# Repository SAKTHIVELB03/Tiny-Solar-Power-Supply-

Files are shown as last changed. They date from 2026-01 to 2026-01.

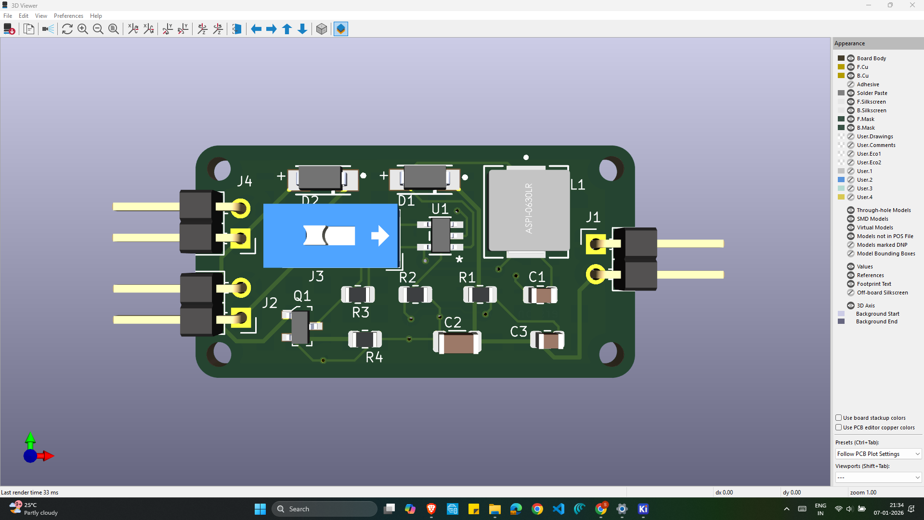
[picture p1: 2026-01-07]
3d model top.png

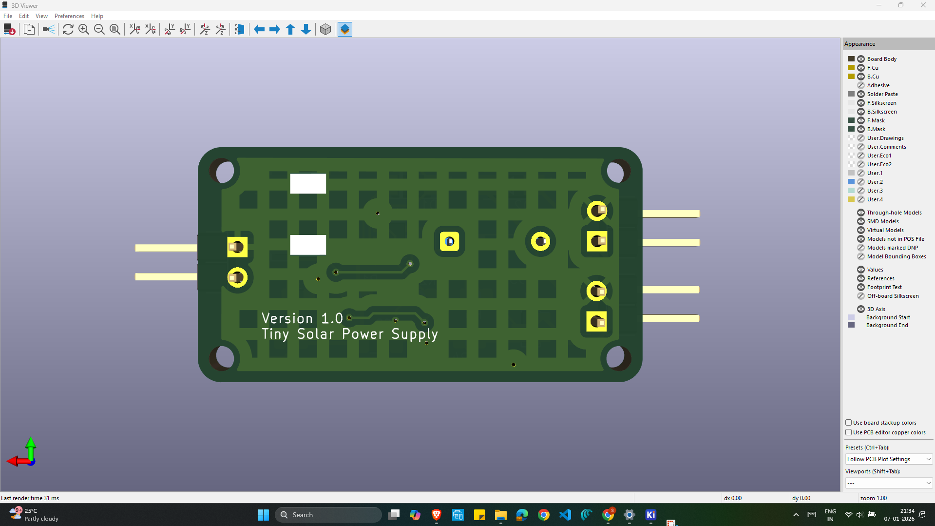
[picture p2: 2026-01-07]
3d model bottom.png

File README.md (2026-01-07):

# Tiny Solar Power Supply – 3.3V Regulated Output

A compact solar-powered power supply that converts energy from a small solar panel and a single 1.2 V Ni-MH AA rechargeable battery into a stable **3.3 V regulated output**, suitable for low-power embedded and IoT applications.

---

## 📌 Overview

This project demonstrates a **low-power boost converter–based solar supply** using the **AP3015/AP3015A micropower DC/DC step-up converter**.  
During daylight, the solar panel charges the battery and disables the boost converter. When light is no longer available, the circuit automatically enables the boost converter and powers the load from the battery.

The design focuses on **efficiency, simplicity, and compact size**, making it ideal for small standalone electronics.

---

## ⚙️ Features

- Regulated **3.3 V output**
- Operates from a **single 1.2 V Ni-MH AA battery**
- Supports **solar charging**
- Automatic **day/night power switching**
- Low-power, high-efficiency design
- Compact PCB footprint

---

## 🔋 How It Works

1. **Daytime Operation**
   - Solar panel charges the Ni-MH battery through a diode.
   - A MOSFET disables the boost converter to prevent unnecessary power loss.

2. **Nighttime Operation**
   - Solar voltage drops.
   - Boost converter is enabled automatically.
   - Battery voltage is stepped up and regulated to **3.3 V**.

The output voltage is set using a resistor feedback network:

---

## 🧩 Main Components

- **AP3015 / AP3015A** – Micropower boost DC/DC converter  
- **2N7002** – MOSFET for automatic switching  
- **SS14** – Schottky diodes  
- **10 µH Inductor**
- Ceramic capacitors (X7R)

---

## 📋 Bill of Materials (BOM)

| Component | Value / Part Number |
|---|---|
| IC1 | AP3015 / AP3015A |
| L1 | 10 µH, ≥680 mA |
| D1, D2 | SS14 |
| T1 | 2N7002 |
| R1 | 1 MΩ |
| R2 | 604 kΩ (1%) |
| R3 | 10 kΩ |
| R4 | 1 MΩ |
| C1 | 4.7 µF |
| C2 | 22 µF |
| C3 | 10 pF |

---

## 🔌 Connections

| Connector | Description |
|---|---|
| K1 | 3.3 V Output |
| K2 | Battery Input |
| K3 | Manual ON/OFF (optional) |
| K4 | Solar Panel Input |

---

## 📐 Files Included

- Schematic
- PCB layout
- Gerber files
- BOM
- Documentation

---

## 🛠 Applications

- Solar-powered IoT devices
- Low-power microcontroller projects
- Environmental sensors
- Educational electronics projects

---

## 📄 Reference

Based on **“Tiny Solar Supply – Sunlight In, 3.3 V Out”**  
Original concept by **Clemens Valens**, Elektor Magazine.

---

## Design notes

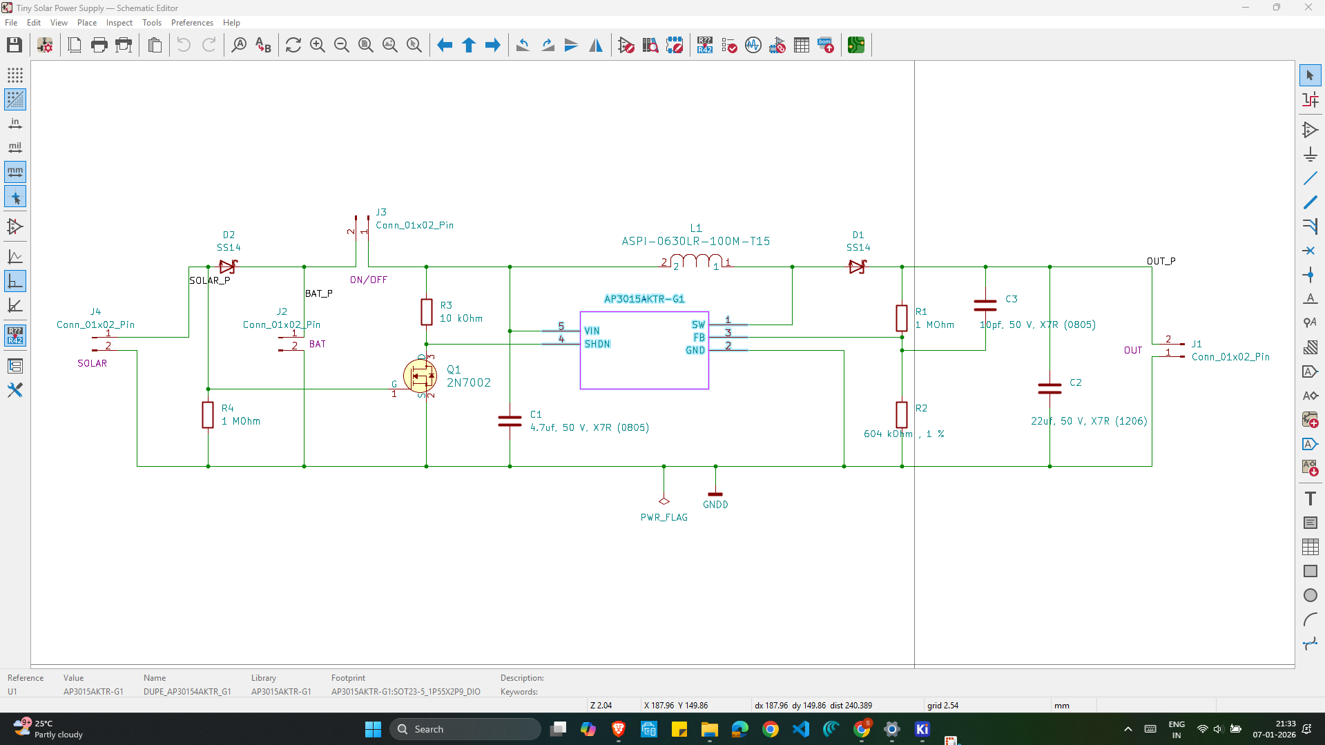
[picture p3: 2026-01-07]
Schematic.png

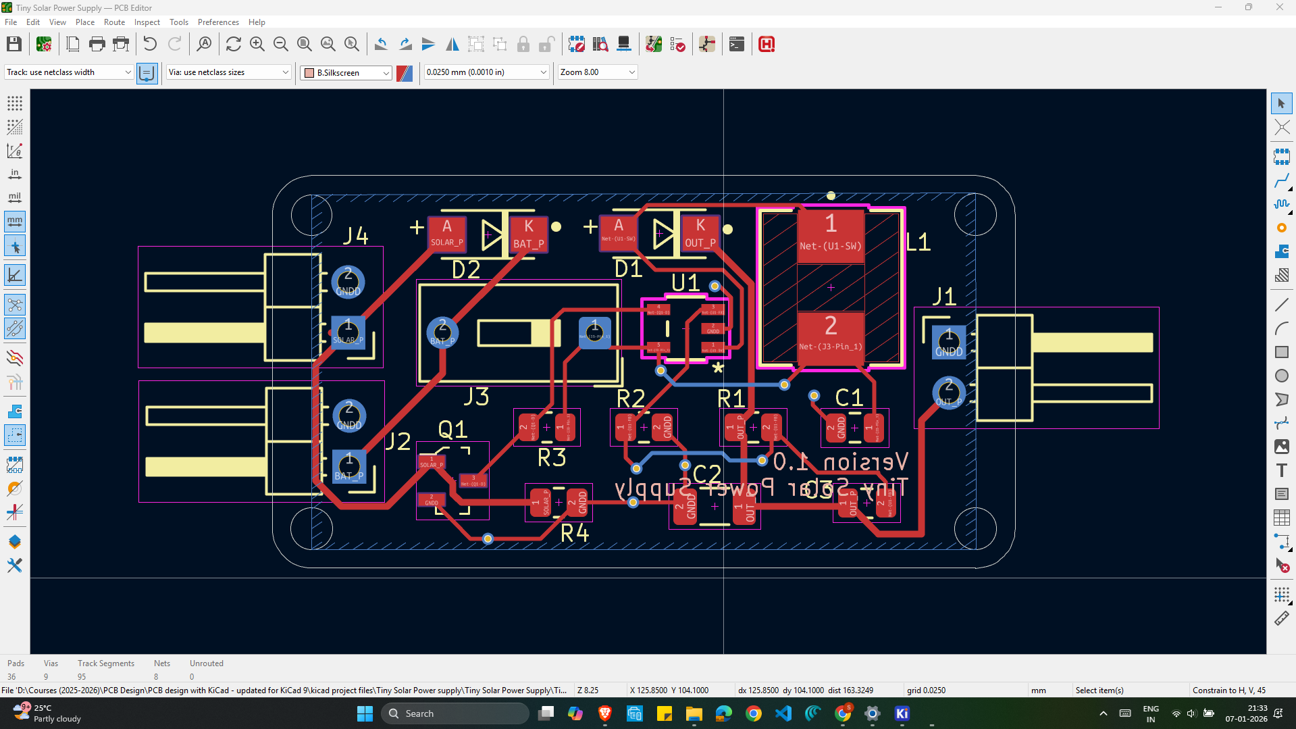
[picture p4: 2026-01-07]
layout.png

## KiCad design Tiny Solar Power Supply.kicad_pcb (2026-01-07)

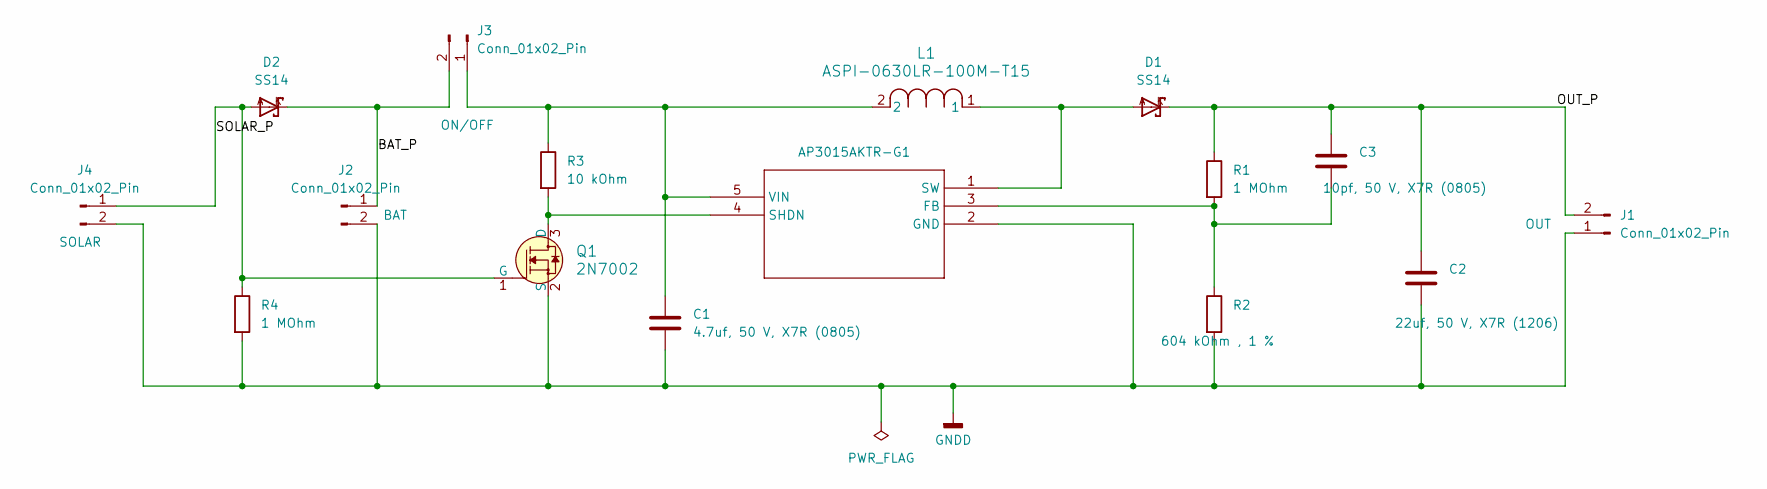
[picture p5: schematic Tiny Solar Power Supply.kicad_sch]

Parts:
C1: 4.7uf, 50 V, X7R (0805); C_0805_2012Metric
C2: 22uf, 50 V, X7R (1206); C_1206_3216Metric
C3: 10pf, 50 V, X7R (0805); C_0805_2012Metric
D1, D2: SS14; DO-214AC
J1, J2, J3: Conn_01x02_Pin; PinHeader_1x02_P2.54mm_Vertical
J4: Conn_01x02_Pin; PinHeader_1x02_P2.54mm_Horizontal
L1: ASPI-0630LR-100M-T15; IND_ASPI-0630LR_ABR
Q1: 2N7002; SOT-23-3; MPN 2N7002; Digi-Key_PN 2N7002NCT-ND
R1, R4: 1 MOhm; R_0805_2012Metric
R2: 604 kOhm , 1 %; R_0805_2012Metric
R3: 10 kOhm; R_0805_2012Metric
U1: AP3015AKTR-G1; SOT23-5_1P55X2P9_DIO

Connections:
/BAT_P: D2.K, J2.1, J3.2
/OUT_P: C2.1, C3.1, D1.K, J1.2, R1.1
/SOLAR_P: D2.A, J4.1, Q1.1 (G), R4.1
GNDD: C1.2, C2.2, J1.1, J2.2, J4.2, Q1.2 (S), R2.2, R4.2, U1.2 (GND)
unnamed: C1.1, J3.1, L1.2, R3.1, U1.5 (VIN)
unnamed: Q1.3 (D), R3.2, U1.4 (SHDN)
unnamed: C3.2, R1.2, R2.1, U1.3 (FB)
unnamed: D1.A, L1.1, U1.1 (SW)

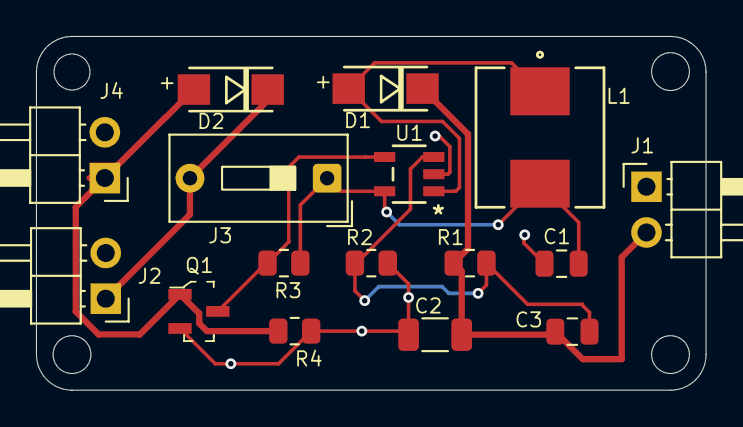
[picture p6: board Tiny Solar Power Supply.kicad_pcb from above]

Board: 2 copper layers, 37.2 x 19.7 mm, 16 parts (0 on the bottom side), 8 nets.

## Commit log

2026-01-07 Enhance README with project details and specifications
    Added detailed project overview, key features, circuit functionality, main components, tools used, applications, and project status.
2026-01-07 Update applications list in README
    Removed 'Breadboard power supply' from applications list.
